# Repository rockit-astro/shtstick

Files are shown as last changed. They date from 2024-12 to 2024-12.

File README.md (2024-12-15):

Firmware and hardware specification for a USB SHT35 temperature/humidity sensor.

### Hardware:

1. Purchase [I2C High Accuracy Temp&Humi Sensor](https://wiki.seeedstudio.com/Grove-I2C_High_Accuracy_Temp%2526Humi_Sensor-SHT35/) ([RS 184-5091](https://uk.rs-online.com/web/p/sensor-development-tools/1845091)) and [XIAO RP2040](https://www.seeedstudio.com/XIAO-RP2040-v1-0-p-5026.html) ([RS 250-0966](https://uk.rs-online.com/web/p/arduino-compatible-boards-kits/2500966)).

2. Wire as follows and cut the top from the wiring connector to reduce its height:

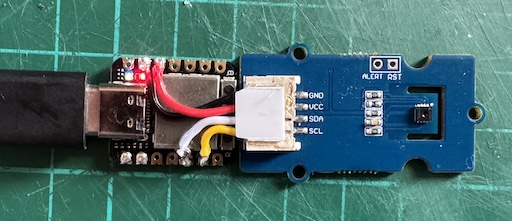
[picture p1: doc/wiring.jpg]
wiring


3. 3D print `shtstick_cap.step` and `shtstick_cover.step`.

4. Install firmware as described below.

5. Assemble electronics in case.

### Compilation/Installation

Requires a working installation of the Raspberry Pi Pico SDK.

Compile the firmware using

```
cd build
cmake ..
make
```

Boot the RP2040 into bootloader mode and copy the generated `shtstick.uf2` to the mounted directory.

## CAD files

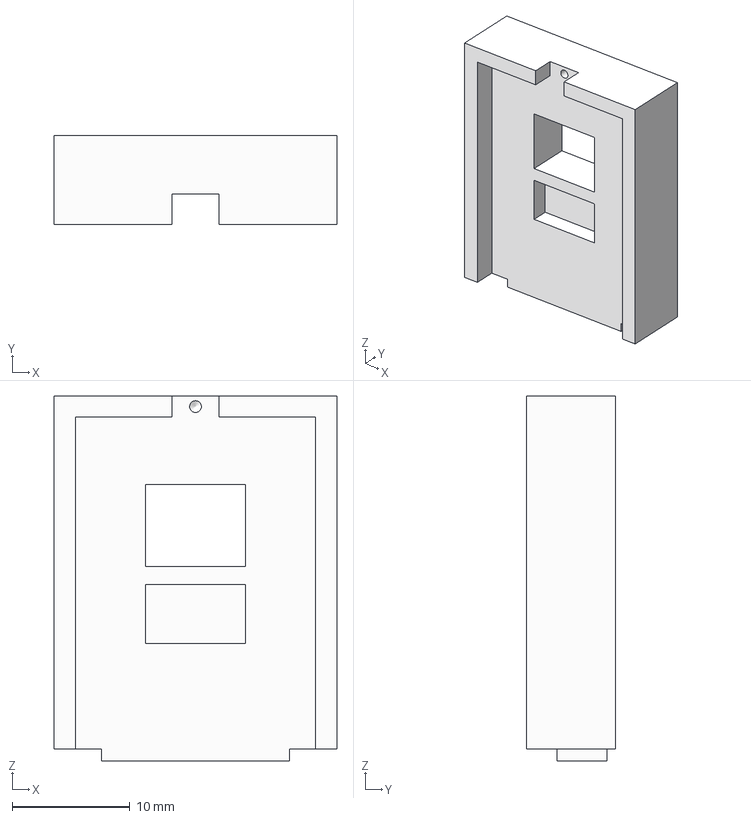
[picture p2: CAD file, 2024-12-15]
shtstick_cover.step
24.0 x 7.60 x 31.0 mm

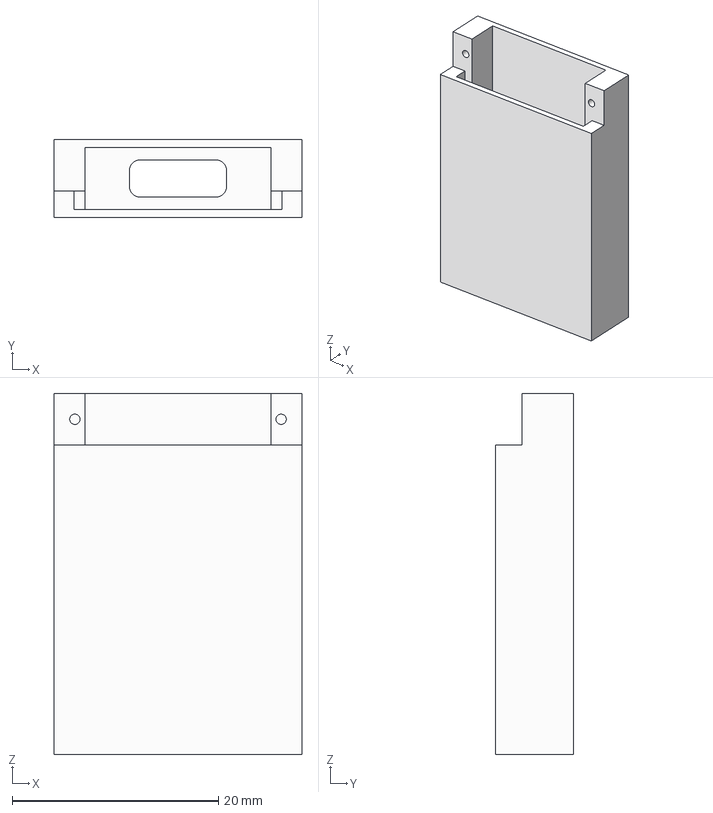
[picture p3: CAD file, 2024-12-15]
shtstick_cap.step
24.0 x 7.60 x 35.0 mm

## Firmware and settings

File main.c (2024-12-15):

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
#include <stdio.h>
#include "pico/binary_info.h"
#include "pico/stdlib.h"
#include "hardware/i2c.h"

uint8_t crc(uint8_t *data, int len)
{
	uint8_t crc = 0xFF;
	for (int i = 0; i < len; i++)
	{
        crc ^= data[i];
        for (int j = 0; j < 8; j++)
            crc = crc & 0x80 ? (crc << 1) ^ 0x131 : crc << 1;
	}

    return crc;
}

int main()
{
    stdio_init_all();

    bi_decl(bi_2pins_with_func(PICO_DEFAULT_I2C_SDA_PIN, PICO_DEFAULT_I2C_SCL_PIN, GPIO_FUNC_I2C));
    bi_decl(bi_program_description("USB SHT35 temperature + humidity sensor"));

    i2c_init(i2c_default, 100000);    
    gpio_set_function(PICO_DEFAULT_I2C_SDA_PIN, GPIO_FUNC_I2C);
    gpio_set_function(PICO_DEFAULT_I2C_SCL_PIN, GPIO_FUNC_I2C);
    gpio_pull_up(PICO_DEFAULT_I2C_SDA_PIN);
    gpio_pull_up(PICO_DEFAULT_I2C_SCL_PIN);

    uint8_t cmd[2] = { 0x24, 0x00 };
    uint8_t data[6];

    while (true) {
        sleep_ms(1000);
        i2c_write_blocking(i2c_default, 0x45, cmd, 2, false);
        sleep_ms(16);
        i2c_read_blocking(i2c_default, 0x45, data, 6, false);

        float temperature = 175 * (data[0] * 256 + data[1]) / 65535. - 45;
        bool temperature_valid = data[2] == crc(data, 2);
        float humidity = 100 * (data[3] * 256 + data[4]) / 65535.;
        bool humidity_valid = data[5] == crc(data + 3, 2);

        if (stdio_usb_connected())
            printf("2R0,Ti=%.1f%s,Ui=%.1f%s\r\n",
                temperature, temperature_valid ? "C" : "#",
                humidity, humidity_valid ? "P" : "#");
    }
}

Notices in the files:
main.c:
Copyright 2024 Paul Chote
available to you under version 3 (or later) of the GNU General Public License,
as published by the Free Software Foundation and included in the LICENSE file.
